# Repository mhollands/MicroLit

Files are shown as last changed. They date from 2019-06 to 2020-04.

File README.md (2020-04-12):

# MicroLit
Simple BBC Microbit based design for controlling lighting from LED strips.

Read more at my website:https://projects.matthollands.com/category/microlit/




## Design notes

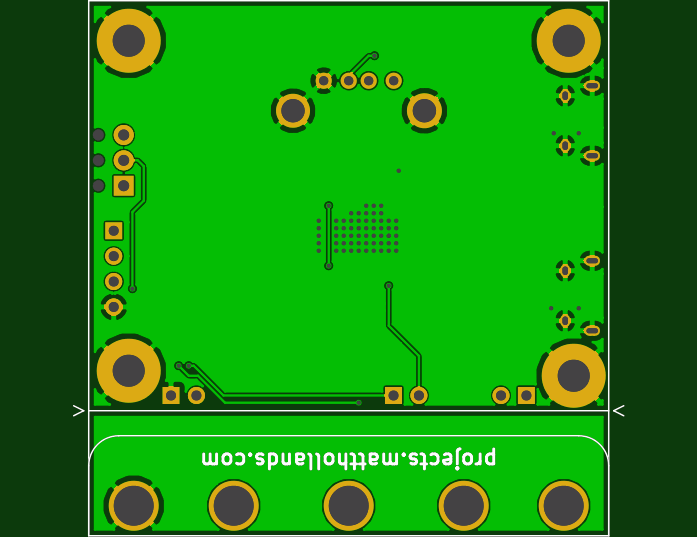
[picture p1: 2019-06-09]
Kicad/MicroLit/Gerbers/V1-bottom.png

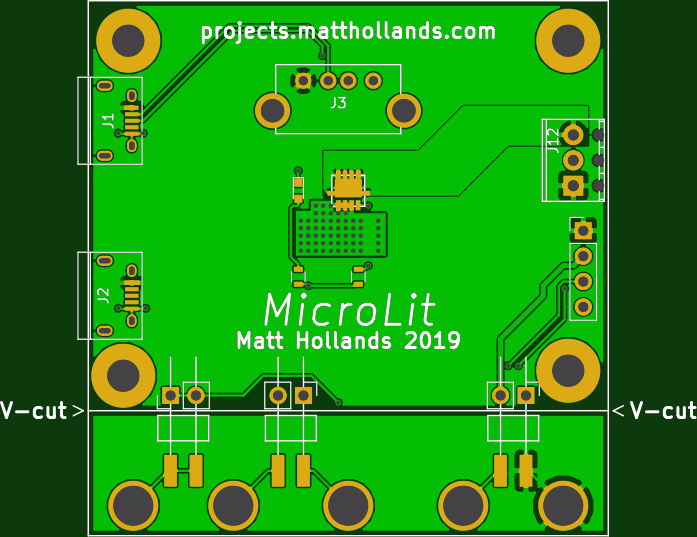
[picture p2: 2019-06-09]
Kicad/MicroLit/Gerbers/V1-top.png

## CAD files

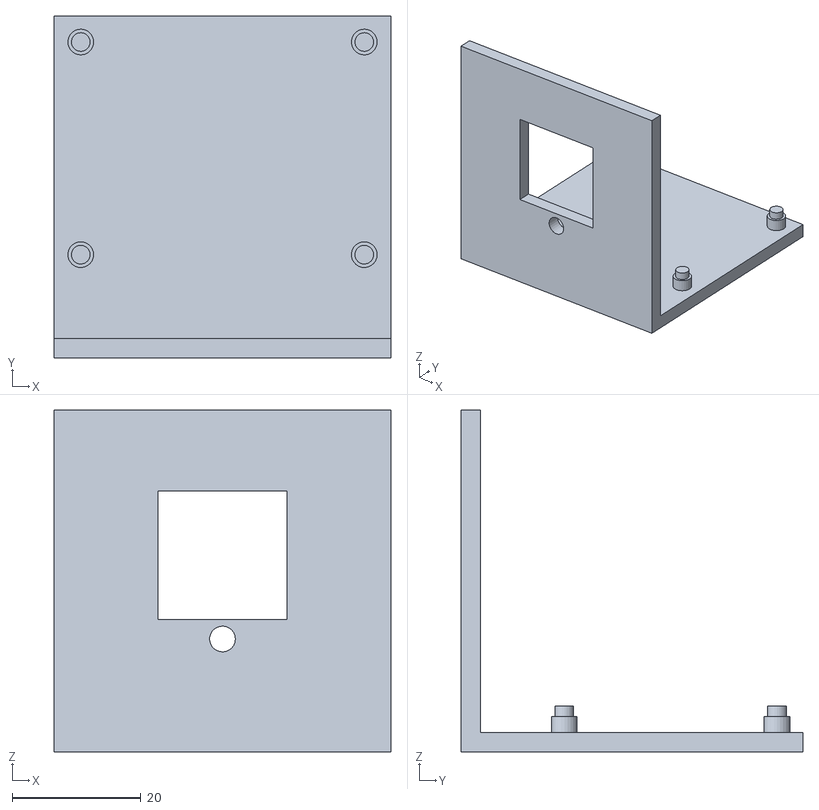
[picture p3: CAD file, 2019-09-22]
3d_print/base.stl
52.3 x 53.0 x 53.0

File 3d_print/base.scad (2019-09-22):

$fn = 25;
base_width = 52.3;
base_length = 50;
base_thickness = 3;
front_height = 47.5;
hole_shift = 4.5;
pcb_hole_rad = 1.45;
pcb_thickness = 1.6;
pcb_stand_off = 2.5;
standoff_rad = 2;
hole_x_separation = 44;
hole_y_separation = 33;
front_hole_radius = 2;
front_hole_offset = 12;
window = 20;
window_offset = 25;

module standoff()
{
	translate([0,0,(pcb_stand_off+pcb_thickness)/2])
		cylinder(r = pcb_hole_rad, h=pcb_stand_off+pcb_thickness, center=true);
	translate([0,0,(pcb_stand_off)/2])
		cylinder(r = standoff_rad, h=pcb_stand_off, center=true);
}

cube([base_width, base_length, base_thickness], center=true);
translate([hole_x_separation/2, hole_y_separation/2+hole_shift, base_thickness/2]) standoff();
translate([-hole_x_separation/2, hole_y_separation/2+hole_shift, base_thickness/2]) standoff();
translate([hole_x_separation/2, -hole_y_separation/2+hole_shift, base_thickness/2]) standoff();
translate([-hole_x_separation/2, -hole_y_separation/2+hole_shift, base_thickness/2]) standoff();

translate([0,-base_length/2-base_thickness/2,(front_height+pcb_stand_off)/2])
	difference()
	{
		cube([base_width, base_thickness, front_height+base_thickness+pcb_stand_off], center=true);
		translate([0,0,-(front_height-base_thickness-pcb_stand_off)/2+window_offset])
			cube([window,base_thickness,window],center=true);
		translate([0,0,-(front_height-base_thickness-pcb_stand_off)/2+front_hole_offset])
			rotate([90,0,0]) cylinder(r=front_hole_radius, h = base_thickness*2, center=true);
	}

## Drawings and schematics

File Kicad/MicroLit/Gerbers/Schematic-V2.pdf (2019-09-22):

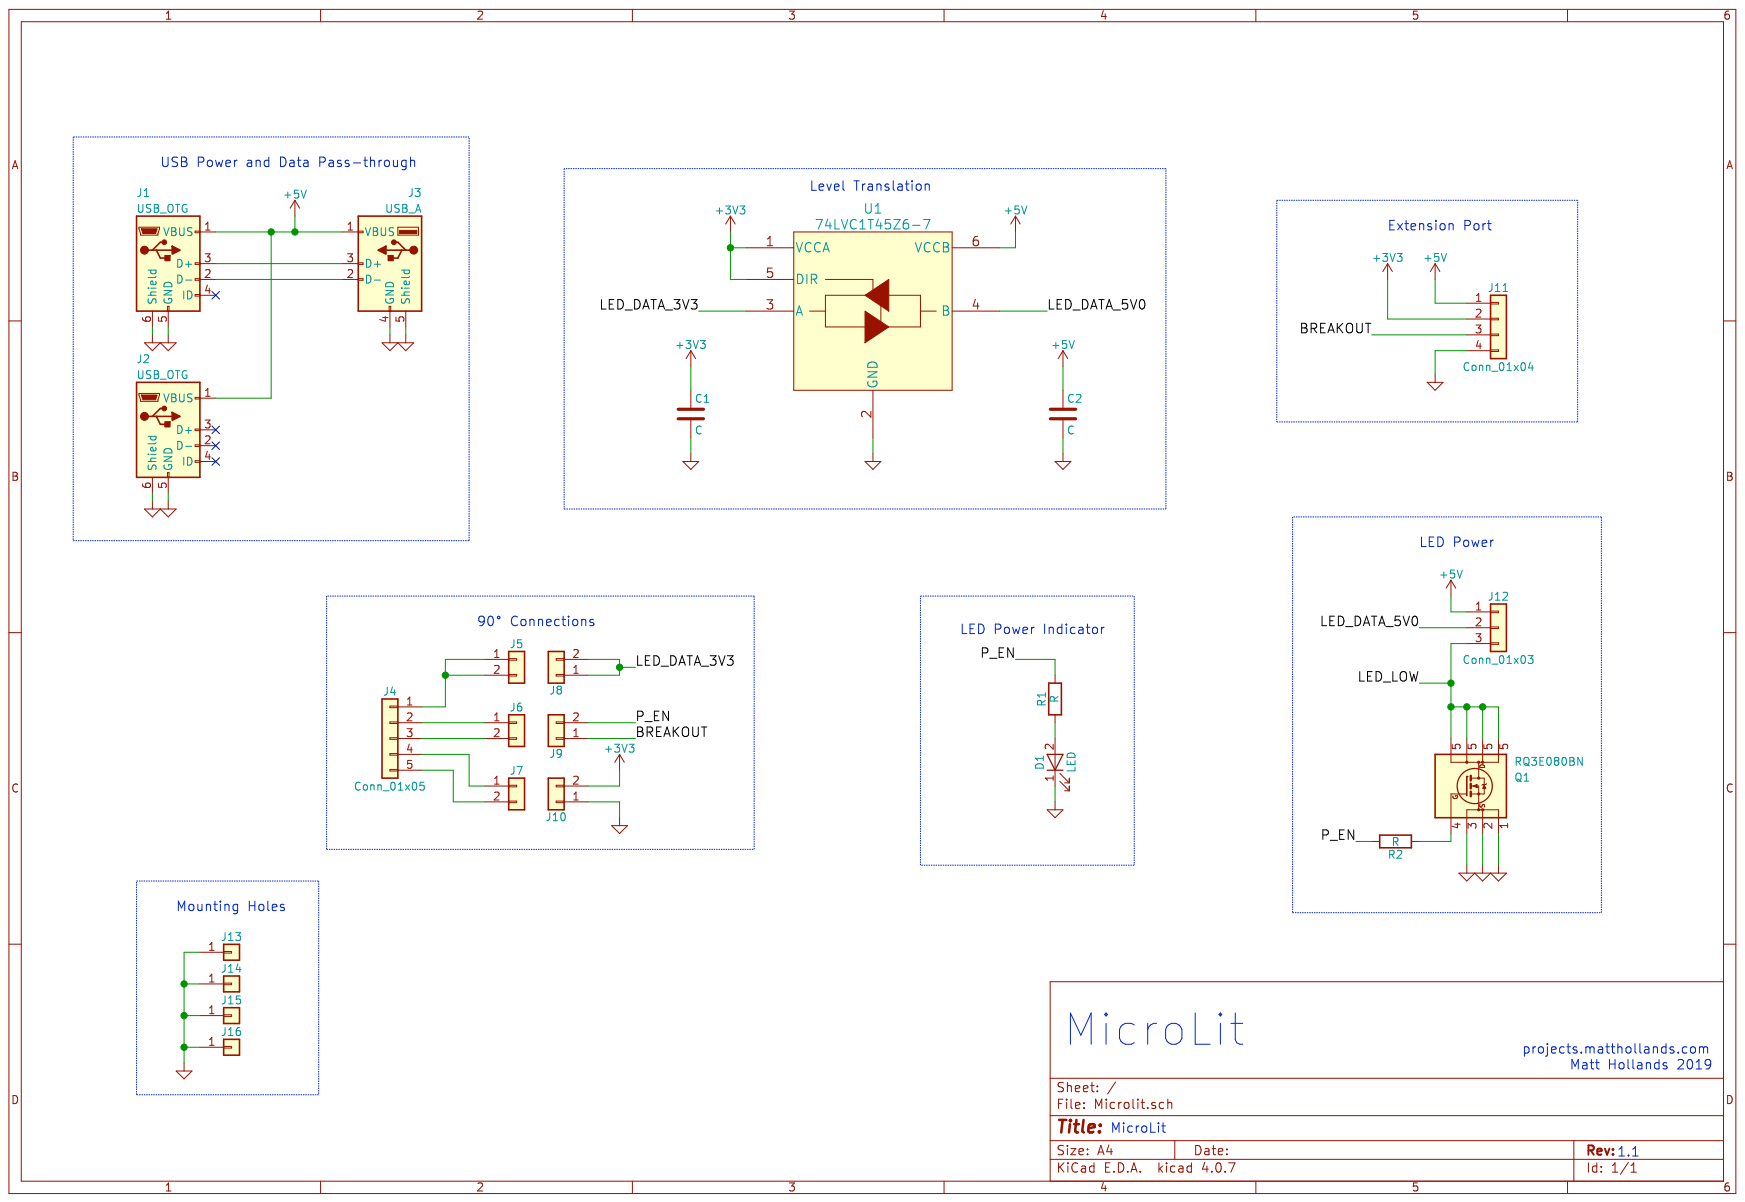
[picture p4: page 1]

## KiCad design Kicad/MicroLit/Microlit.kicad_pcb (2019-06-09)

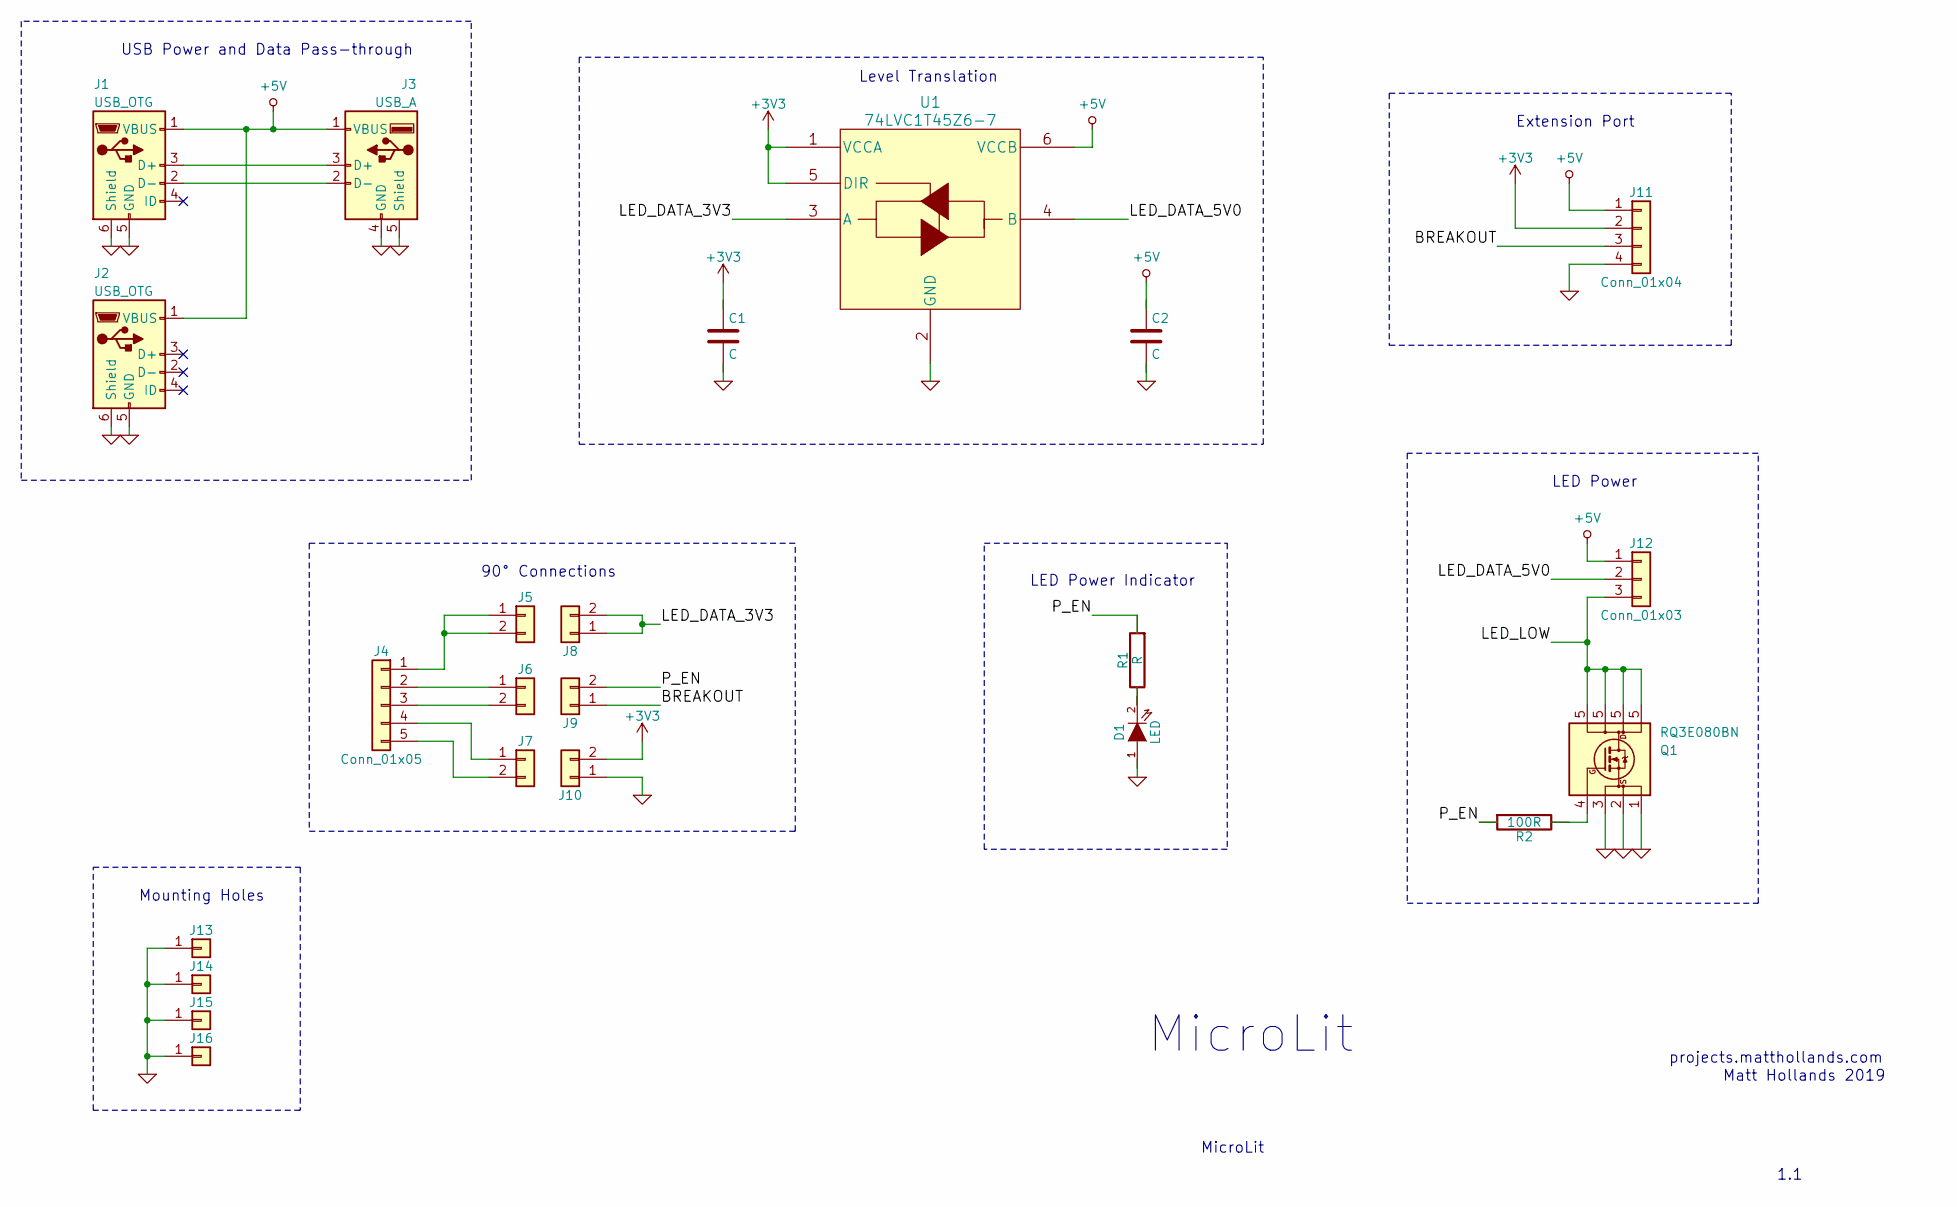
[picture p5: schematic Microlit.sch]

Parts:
C1, C2: C; C_0603
D1: LED; LED_0603
J1, J2: USB_OTG; USB_Micro-B
J3: USB_A; USB_A_Vertical
J4: Conn_01x05; MICROBIT_Bolt_On
J5, J6, J7: Conn_01x02; TSM-102-01-T-SH
J8, J9, J10: Conn_01x02; Pin_Header_Straight_1x02_Pitch2.54mm
J11: Conn_01x04; Pin_Header_Straight_1x04_Pitch2.54mm
J12: Conn_01x03; TerminalBlock_Phoenix_MPT-2.54mm_3pol
J13, J14, J15, J16: Conn_01x01; MountingHole_3.2mm_M3_Pad
Q1: RQ3E080BN; HSMT8
R1: R; R_0603
R2: 100R; R_0603
U1: 74LVC1T45Z6-7

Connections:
+3V3: C1.1, J10.2, J11.2, U1.1 (VCCA), U1.5 (DIR)
+5V: C2.1, J1.1 (VBUS), J2.1 (VBUS), J3.1 (VBUS), J11.1, J12.1, U1.6 (VCCB)
/BREAKOUT: J9.1, J11.3
/LED_DATA_3V3: J8.1, J8.2, U1.3 (A)
/LED_DATA_5V0: J12.2, U1.4 (B)
/LED_LOW: J12.3, Q1.5 (D)
/P_EN: J9.2, R1.1, R2.1
GND: C1.2, C2.2, D1.1 (A), J1.5 (GND), J1.6 (Shield), J2.5 (GND), J2.6 (Shield), J3.4 (GND), J3.5 (Shield), J10.1, J11.4, J13.1, J14.1, J15.1, J16.1, Q1.1 (S), Q1.2 (S), Q1.3 (S), U1.2 (GND)
unnamed: D1.2 (K), R1.2
unnamed: J1.2 (D-), J3.2 (D-)
unnamed: J1.3 (D+), J3.3 (D+)
unnamed: J4.1, J5.1, J5.2
unnamed: J4.2, J6.1
unnamed: J4.3, J6.2
unnamed: J4.4, J7.1
unnamed: J4.5, J7.2
unnamed: Q1.4 (G), R2.2

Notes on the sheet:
MicroLit
1.1
Matt Hollands 2019
projects.matthollands.com
USB Power and Data Pass-through
Level Translation
90° Connections
LED Power
Mounting Holes
Extension Port
LED Power Indicator

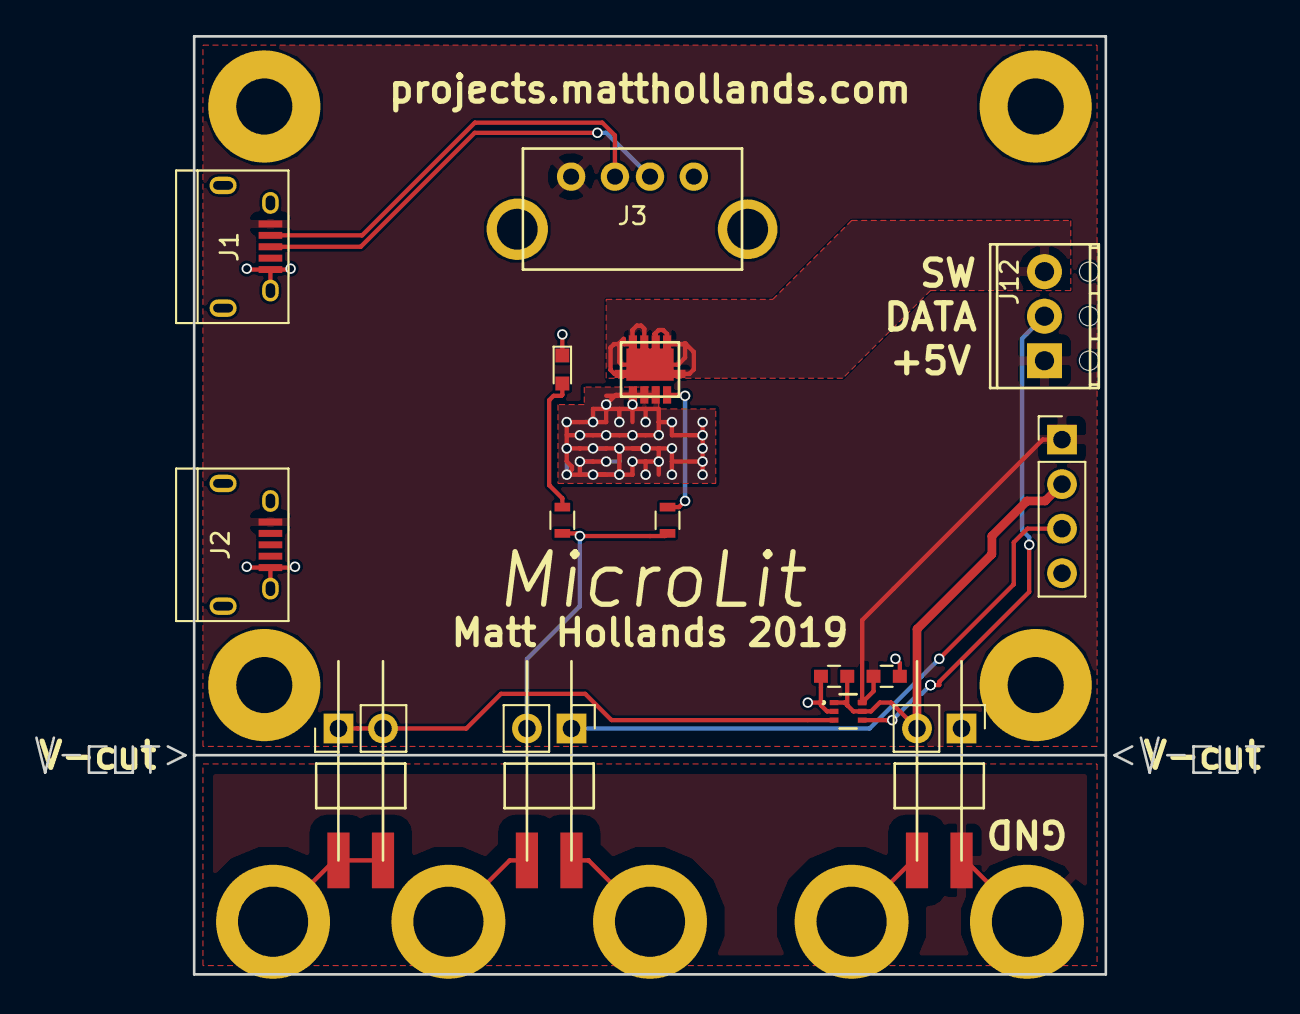
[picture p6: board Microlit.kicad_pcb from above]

Board: 2 copper layers, 52.0 x 53.5 mm, 23 parts (1 on the bottom side), 17 nets.

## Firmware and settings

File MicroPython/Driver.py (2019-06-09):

from microbit import *
import radio
import utime
import neopixel

radio.on()
np = neopixel.NeoPixel(pin0, 100)

colours = [[255,0,0], [0,255,0], [0,0,255], [255,255,0], [255, 0, 255], [0,255,255], [255,255,255]]

def turnOnLEDs():
	pin1.write_digital(1)

def turnOffLEDs():
	pin0.write_digital(1)
	pin1.write_digital(0)

def drawLight():
	global colours
	global setting
	for i in range(0,len(np)):
		np[i] = colours[setting%len(colours)-1]  # first element
	np.show()

turnOnLEDs()

setting = 0
while True:
	incoming = radio.receive()
	if(incoming is not None):
		if(int(incoming) >= 0 and int(incoming) <= 10):
			setting = int(incoming)
			radio.send(str(setting))

	if(setting == 0):
		turnOffLEDs()
		display.clear()
	else:
		turnOnLEDs()
		drawLight()
		display.show(setting)

#setting = 0
#while True:
#    incoming = radio.receive()
#    if(incoming is not None):
#    	setting = int(incoming)
#    	radio.send(str(setting))
#    display.show(setting)##

    #if(setting == 0):
   # 	turnOffLEDs()
   # else:
   # 	drawLight()
   # 	utime.sleep_ms(500)

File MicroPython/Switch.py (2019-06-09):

from microbit import *
import radio
import utime

target = 0
remote = 0

while True:
	if(target != remote):
		radio.on()
		radio.send(str(target))
		display.set_pixel(4,4,9)
		incoming = radio.receive()
		if(incoming is not None):
			remote = int(incoming)
	else:
		radio.off()
		display.set_pixel(4,4,0)

	if button_a.was_pressed():
		target = target - 1
	if button_b.was_pressed():
		target = target + 1
	display.show(target)

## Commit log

2019-06-09 Added kicad files and micropython code
    [Microlit-B.Cu.gbr, Microlit-B.Mask.gbr, Microlit-B.SilkS.gbr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]
2019-09-22 update for v2
    [Microlit.sch]
2019-09-22 added CAD for enclosure
    [base.scad, base.stl]

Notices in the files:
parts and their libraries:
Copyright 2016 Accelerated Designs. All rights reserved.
